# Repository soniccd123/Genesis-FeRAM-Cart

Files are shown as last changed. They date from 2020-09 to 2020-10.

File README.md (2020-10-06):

# Genesis FeRAM Cart
A open Sega Genesis cartridge PCB with save feature

This projects uses a 27C322 4MB EPROM Chip and a FM1808 32KB FeRAM as save storage. It was developed in KiCAD and tested in real hardware.

In the actual state, this cartridge features:

- Suports Genesis and 32X software
- ROM Support for up to 4MB
- Save support for all ROM sizes (Selection for <2MB/4MB by jumper)
- 32KB of FeRAM for saving
- No need for battery for saving
- Rudimentary ROM bank switch (Permits multiple games on same ROM)

This project is possible thanks to TmEE (NESdev Forums, SRAM wiring schematics) and Rene Richard (db-electronics on GitHUB, KiCAD libs for the Genesis cart connector).

# Component List:
- U1 74HC74;
- U2 FM1808B;
- U3 74HC139 (or LS);
- U4 27C322 (May use other 27CXX memories with some minor modifications);
- R1, R2, R3, R4 1K Resistors;
- SW1 4 channel DIP Switch;
- C1, C2, C3 10nF Capacitors;

# How to use:
Bank Switching: The user may write multiple roms to the same EPROM, the DIP switch controls which area of the EPROM is read by the Genesis/Mega Drive; The minimum bank size is 256KB. Each of the switches connect a memory address line between the system and the EPROM: when the switch is on, the respective address line is controlled by the Sega Genesis; When off, the EPROM adress line is pulled-up and cut from Genesis control. the address lines are A20, A19, A18, A17 (considering LSB as A0). To select the desired bank, turn the switches on and off acordingly to the begining address that the ROM occupies in the EPROM.

Examples:

ROM_x begin at 0x100000 -> Switch just A19 off (pull-up);           
ROM_y begin at 0x180000 -> Switch A19 and A18 off;

This technique may not be compatible with save supporting Genesis software.

How to make multirom file: Just use the CMD command "copy /b rom_x.bin + rom_y.bin + rom_z.bin rom_result.bin" to join them to one file. One may join how many ROMs he wants to, just be shure that the result file is smaller than the total size of the EPROM and that the ROMs fit correctly to each desired bank to make software switching possible.

JP1 jumper: This jumper is the result of some tests with varied sized Save RAM suporting software. This jumper is necessary for software bigger or smaller than 2MB to correctly save and detect the FeRAM. For software bigger than 2M, one must connect (with solder blob, 0K resistor, etc) the >2MB part of the jumper; for smaller or equal to 2MB software, one must do the same with the <2MB part of the jumper.

Other than that, just write to your EPROM and happy playing!

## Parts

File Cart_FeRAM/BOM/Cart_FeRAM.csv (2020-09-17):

Reference | Quantity | Value | Footprint | Datasheet
C1 C2 C3 C4 C5 C6 | 6 | C | Connector_PinHeader_2.54mm:PinHeader_1x02_P2.54mm_Vertical | ~
CON1 | 1 | GENESIS-EDGE | db-smt:GENESIS-EDGE
J1 J2 | 2 | Conn_01x32_Male | Connector_PinSocket_2.54mm:PinSocket_1x32_P2.54mm_Vertical | ~
JP1 | 1 | <2M/4M | Jumper:SolderJumper-3_P1.3mm_Open_Pad1.0x1.5mm | ~
R4 R3 R2 R1 | 4 | 1K | Resistor_THT:R_Axial_DIN0207_L6.3mm_D2.5mm_P7.62mm_Horizontal | ~
SW1 | 1 | SW_DIP_x04 | Button_Switch_THT:SW_DIP_SPSTx04_Slide_9.78x12.34mm_W7.62mm_P2.54mm | ~
U1 | 1 | 74HC74 | Package_DIP:DIP-14_W7.62mm | 74xx/74hc_hct74.pdf
U2 | 1 | FM1808B-SG | Package_SO:SOIC-28W_7.5x17.9mm_P1.27mm | http://www.cypress.com/file/136521/download
U3 | 1 | 74LS139 | Package_DIP:DIP-16_W7.62mm
U4 | 1 | 27C322 | Package_DIP:DIP-42_W15.24mm_Socket

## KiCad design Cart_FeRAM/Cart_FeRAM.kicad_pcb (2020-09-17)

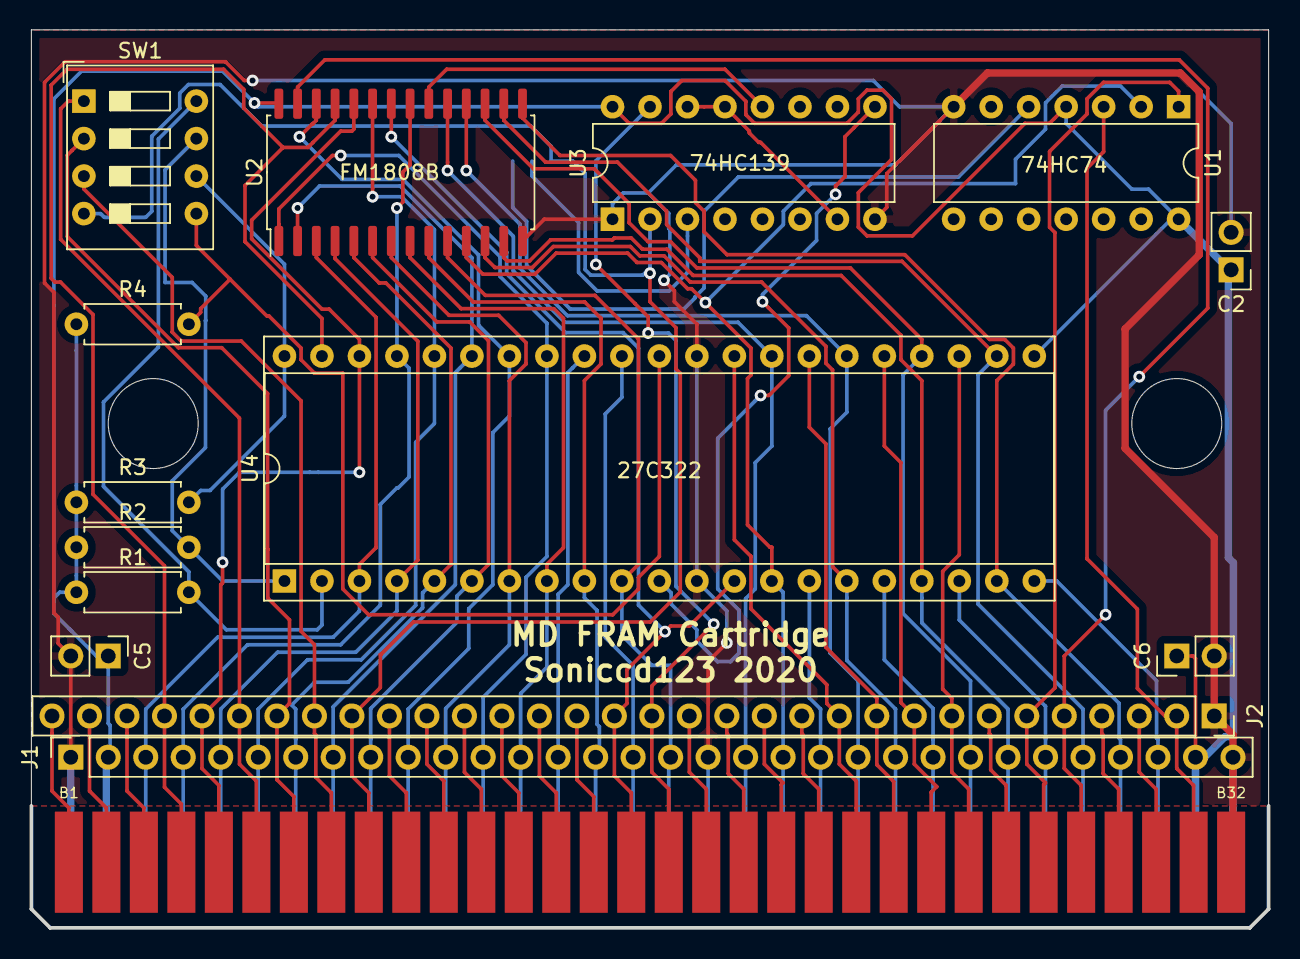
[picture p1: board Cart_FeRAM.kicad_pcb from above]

Board: 2 copper layers, 83.8 x 60.8 mm, 16 parts (1 on the bottom side), 69 nets.

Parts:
C2, C5, C6: C; PinHeader_1x02_P2.54mm_Vertical
CON1: GENESIS-EDGE
J1, J2: Conn_01x32_Male; PinSocket_1x32_P2.54mm_Vertical
JP1: <2M/4M; SolderJumper-3_P1.3mm_Open_Pad1.0x1.5mm
R1, R2, R3, R4: 1K; R_Axial_DIN0207_L6.3mm_D2.5mm_P7.62mm_Horizontal
SW1: SW_DIP_x04; SW_DIP_SPSTx04_Slide_9.78x12.34mm_W7.62mm_P2.54mm
U1: 74HC74; DIP-14_W7.62mm
U2: FM1808B-SG; SOIC-28W_7.5x17.9mm_P1.27mm
U3: 74LS139; DIP-16_W7.62mm
U4: 27C322; DIP-42_W15.24mm_Socket

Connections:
+5V: C2.1, C5.1, C6.1, CON1.A2, CON1.A31, J1.2, J1.31, R1.1, R2.1, R3.1, R4.1, U1.4, U1.14, U2.28, U3.16, U4.22
/A0: CON1.A17, J1.17, U2.10, U4.10
/A1: CON1.A15, J1.15, U2.9, U4.9
/A2: CON1.A13, J1.13, U2.8, U4.8
/A3: CON1.A11, J1.11, U2.7, U4.7
/A4: CON1.A9, J1.9, U2.6, U4.6
/A5: CON1.A7, J1.7, U2.5, U4.5
/A6: CON1.A5, J1.5, U2.4, U4.4
/A7: CON1.A3, J1.3, U2.3, U4.3
/A8: CON1.B4, J2.29, U2.25, U4.41
/A9: CON1.B5, J2.28, U2.24, U4.40
/A10: CON1.A4, J1.4, U2.21, U4.39
/A11: CON1.A6, J1.6, U2.23, U4.38
/A12: CON1.A8, J1.8, U2.2, U4.37
/A13: CON1.A10, J1.10, U2.26, U4.36
/A14: CON1.A12, J1.12, U2.1, U4.35
/A15: CON1.A14, J1.14, U4.34
/A16: CON1.A16, J1.16, U4.33
/A17: R1.2, SW1.8, U4.2
/A18: R2.2, SW1.7, U4.1
/A19: R3.2, SW1.6, U4.42
/A20: R4.2, SW1.5, U4.32
/CART_A17: CON1.B6, J2.27, SW1.1
/CART_A18: CON1.B7, J2.26, SW1.2
/CART_A19: CON1.B8, J2.25, SW1.3
/CART_A20: CON1.B9, J2.24, JP1.1, SW1.4, U3.2
/CE: CON1.B17, J2.16, U3.15
/D0: CON1.A20, J1.20, U1.2, U2.11, U4.14
/D1: CON1.A23, J1.23, U2.12, U4.16
/D2: CON1.A26, J1.26, U2.13, U4.18
/D3: CON1.A29, J1.29, U2.15, U4.20
/D4: CON1.A28, J1.28, U2.16, U4.23
/D5: CON1.A25, J1.25, U2.17, U4.25
/D6: CON1.A22, J1.22, U2.18, U4.27
/D7: CON1.A19, J1.19, U2.19, U4.29
/D8: CON1.A21, J1.21, U4.15
/D9: CON1.A24, J1.24, U4.17
/D10: CON1.A27, J1.27, U4.19
/D11: CON1.A30, J1.30, U4.21
/D12: CON1.B25, J2.8, U4.24
/D13: CON1.B24, J2.9, U4.26
/D14: CON1.B23, J2.10, U4.28
/D15: CON1.B22, J2.11, U4.30
/OE: CON1.B16, J2.17, U2.22, U4.13
/RESET: CON1.B27, J2.6, U1.1
/ROM_CE: U3.9, U4.11
/SRAM_CE: U2.20, U3.12
/TIME: CON1.B31, J2.2, U1.3
/WE: CON1.B28, J2.5, U2.27
GND: C2.2, C5.2, C6.2, CON1.A1, CON1.A18, CON1.A32, CON1.B32, J1.1, J1.18, J1.32, J2.1, U1.7, U2.14, U3.1, U3.8, U4.12, U4.31
unnamed: CON1.B1, J2.32
unnamed: CON1.B2, J2.31
unnamed: CON1.B3, J2.30
unnamed: CON1.B10, J2.23
unnamed: CON1.B11, J2.22
unnamed: CON1.B12, J2.21
unnamed: CON1.B13, J2.20
unnamed: CON1.B14, J2.19
unnamed: CON1.B15, J2.18
unnamed: CON1.B18, J2.15
unnamed: CON1.B19, J2.14
unnamed: CON1.B20, J2.13
unnamed: CON1.B21, J2.12
unnamed: CON1.B26, J2.7
unnamed: CON1.B29, J2.4
unnamed: CON1.B30, J2.3
unnamed: JP1.2, U3.3
unnamed: JP1.3, U1.5
unnamed: U3.7, U3.13, U3.14

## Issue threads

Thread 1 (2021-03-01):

What license does this project use? Would like to re-use the cart edge connector.

darrena092, 2021-03-01:
Hi there!

Sorry to be a pain, but can you let me know what license you're using for this project? I'm working on a (soon to be) open source Genesis/Megadrive cart, and would like to reuse the cart edge connector component you've made if you would be okay with that. Looks like really great work.

Thanks so much!
Darren

soniccd123, 2021-03-01:
Hello, I'm still which licence to use, sorry for the inconvenient. Still, don't worrky about the cart edge connector, this part was made by René Richard and its available in his console parts kicad library, licenced with CERN OHL. Here is the repository: https://github.com/db-electronics/kicadlib

darrena092, 2021-03-02:
Thanks for that!

Closed 2021-03-02.

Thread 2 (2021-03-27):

Games not save

CristianCG86, 2021-03-27:
Hi!!

I loved this project. I have been looking for something like this for a long time, thank you.

But I tried saving system with the games Phantasy Star IV and Beyond Oasis, but they didn't save my game. I have checked all the assembly, the position of the components, the position of the jumper, but I don't see any failure in the assembly. I loved this project. I have been looking for something like this for a long time, thank you.

But I have tried saving in FRAM and with the games Phantasy Star IV and Beyond Oasis, but they didn't save my game. I have checked all the assembly, the position of the components, the position of the jumper, but I don't see any failure in the assembly. Has it also happened to you?

Regards

soniccd123, 2021-03-30:
Hey!

About Beyond Oasis specifically, did you soldered the jumper to >2MB position? It should work, I've made a repro myself and been playing it.

About Phantasy Star IV and Tänzer, never tested them, maybe try diferent jumper positions, some games, even though being <2MB in size, use the same save system as games bigger than 2MB.

Also, be sure that the FRAM chip is correctly soldered, try testing its pins continuity, I've had problems with saving before because the chip had one pin that was not making contact.

12manu12, 2025-02-22:
Hi, i am testing with this pcbs and I have the same, testes with beyond Oasis (Story of Thor) and the game not save.
Did you manage to fix it and make it work?

I used 74LS139N instead of 74HC139. Can this be mixed with 74HC74 or do you need 74LS74 to work as well?
The FRAM used is FM18W08.
The jumper has pins 2 and 3 connected on the back of the board.
I attach a photo.

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

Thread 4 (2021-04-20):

Question about ROM programming

wilianpc, 2021-04-20:
Hi! Congratulations for this beautiful project. Sorry if these are noob questions, but there they go:
When writing in the EPROM, should i byte-swap the ROM?
If i use a regular SRAM (ex. CY62256) with battery, should i keep the pin order (A0...A14)?

soniccd123, 2021-04-23:
Hey man, thanks!!! Don't worry, every question is welcome

Yes, you should, most  common Genesis ROMs formats are byteswapped for some reason.

About the SRAM, I supose that it should work, but I never tried, I also supose that you will implement the battery circuit yourself right?

wilianpc, 2021-04-30:
Thanks for your kindness! Yeah, It's a popular common-emitter transistor circuit, with two face-to-face diodes as the "VCC" for the SRAM.

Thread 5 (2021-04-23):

27c160

Indibilio, 2021-04-23:
Hello! How i can use a 27c160 EEPROM whit this cartridge? Which modifications it needs?

Thanks.

soniccd123, 2021-04-24:
Hello! Yes it should work, just put turn A20 off in the switch (switch photo with A20 marked for reference is attached to this message), this will garantee that the 27C160 Byte pin is high, setting it to 16bit mode and will disconnect this pin from the Genesis Cart bus.

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

Indibilio, 2021-04-24:
Thanks for the reply. I thought I had to cut a track. So I turn OFF that switch in that position, and the cartridge already works with EEPROM 27c160 and lower.

Great job!!!

Indibilio, 2021-05-23:
Hello. Another question. The FM1808 is discontinued and its price is increased.

It is possible to use another equivalent fram? Or if i don't use the 3 top switch to use another memory banks, it is possible to use a small fram memory type? Only one game - one save bank.

Thanks!!!!☺️☺️

soniccd123, 2021-05-27:
Yes, you can use a equivalent as long as it is pin compatible and 5V tolerant. I personally use the FM18W08 which is mostly identical and is widely available.

You can also use a smaller FeRAM if you want, but need to check if it is pin compatible, I don't really have any chips to recommend, but they surely exist.

Indibilio, 2021-06-11:
Thanks.

It is dificult to modiffy this pcb to allow two 27c322 and put the rom of "Pier Solar" inside? Using the mapper to play a game with 64mb with save feature. This game is sold out, not disponible, and dificult to play into a real hardware.

soniccd123, 2021-11-01:
Hey! Sorry for the making you wait so much, life got in the way and its been some time i didn't check my github.

Well, it is perfectly possible if you can implement the mapper. I really don't know much about how Pier Solar maps the 64Mb, is it a SSF mapper? Really depends on how much space the circutry takes, but should be doable.

Indibilio, 2021-11-01:
I think it will be complicated, I don't know how the Pier Solar mapper works, I only have a slight knowledge of electronics. I thought that using two 27c322s together with a traditional mapper could be done. The Chinese on Aliexpress do it, but I don't know how.

Courage, life sometimes gets difficult, but don't forget to live !!!

PicoElements, 2022-08-30:
Hi! I love this project! I'm trying to make it work with a 27c160 and i saw the first comment so very helpful! All the switches on but the A20. Cn it work without the FM18W08 ? Is there a way not to use it? It's really hard to find.
Thanks a lot!

Indibilio, 2022-09-03:
You can find the FM18W08 or FM1808 from Aliexpress....

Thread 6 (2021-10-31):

Cartridge mod for 32X

Indibilio, 2021-10-31:
Hello, can you offer a variant with the holes moved to fit into a 32x cartridge? Only is need to move the holes, the PCB works great!!

Thanks for your job!

soniccd123, 2021-11-01:
Hey friend, I'll take a look, can you take the measurements and send to me? I don't have any 32X game with me right now. I'm living in a city far away from my home for work reasons for the next 2 months, so no way of doing it myself right now.

Indibilio, 2021-11-01:
Thanks for resonder. I tried to move them with kicad but everything moved !!! I don't know how to use kicad, sorry.

I will take measurements of the holes, you have to separate them more. They are 81mm apart. Each hole has to be moved 6mm out. They are then out of the PCB, but only that there is a curve left, I think it will hold.

If it's a lot of work, forget it.

I have made some homemade cartridges with hack roms for my use, I thank you very much for your work !!

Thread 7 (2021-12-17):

Solder Jumper CART_A20 line

RetroWizzard, 2021-12-17:
First of all, thank you so much for creating this cartridge.

There seems to be an inconsistency between the schematic and the pcb.
When you update the pcb from the schematic KiCAD wants to reconnect (or rather invert) the pin connections from the solder jumper to U3.
It shows two messages:
Reconnect U3 pin 2 from /CART_A20 to Net-(JP1-Pad2).
Reconnect U3 pin 3 from Net-(JP1-Pad2) to /CART_A20.

So I was wondering which one is correct, the schematic or the pcb?
Thanks for your help

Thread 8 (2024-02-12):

PCB thickness

DevDavisNunez, 2024-02-12:
Hello @soniccd123,

First of all, excellent work, and thank you very much for sharing it!

Now, I wanted to try to manufacture it, but what thickness of plate is required? Is beveling required? 20° or more?

Thanks!

rinemetal, 2024-09-07:
For genesis run 1.6 board thickness and 30 for the beveling

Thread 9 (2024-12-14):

chips orientation

Risc2m, 2024-12-14:
The chip orientation on the pcb is correct???

Whats the fm1808 pin one position'??

Thanks a lot for your work

12manu12, 2025-03-08:
have you solved it? my game works but not save game

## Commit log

2020-08-02 Updated board design, some project clean up
    [Cart_FeRAM.kicad_pcb, Cart_FeRAM.sch]
2020-08-02 Updated PCB production files acording to latest design changes
    [Cart_FeRAM-B_Cu.gbr, Cart_FeRAM-B_Mask.gbr, Cart_FeRAM-B_Paste.gbr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]
2020-09-17 Added IC values to silkscreen, added JP1 identification to silkscreen, added BOM
    [Cart_FeRAM.csv, Cart_FeRAM.kicad_pcb]
